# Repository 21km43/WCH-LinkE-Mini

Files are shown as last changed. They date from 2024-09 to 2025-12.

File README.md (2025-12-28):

# WCH-LinkE-Mini

This project is compatible with WCH-LinkE.

Boards is optimized for [JLCPCB](https://jlcpcb.com) (includes gerber, bom, cpl, and tooling holes). All components except the CH32V305, USB-C Connector, 3.3V LDO, and Tactile switches are Basic Parts.

## Requirements
* [KiCAD 9.0](https://www.kicad.org/)
* [Fabrication-Toolkit (Optional)](https://github.com/bennymeg/Fabrication-Toolkit)

## LICENSE
[MIT LICENSE](/LICENSE)

## Production files
- [Gerber](/production/WCH-LinkE-Mini_v1.4.0.zip)
- [BOM](/production/bom.csv)
- [Parts List](/production/bom.csv)

## Schematic and Board image
[Board schematic](WCH-LinkE-Mini.pdf)  
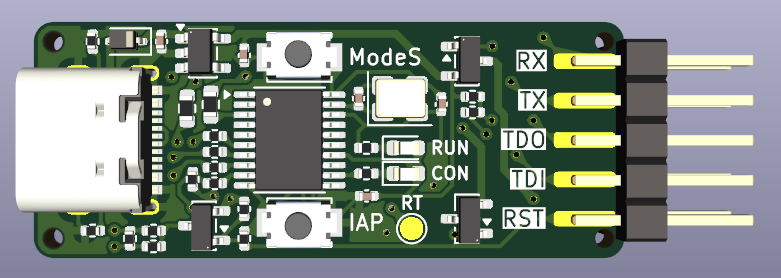
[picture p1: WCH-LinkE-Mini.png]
Board Image


IDC Connectors are available here
- [IDC-Header(socket)](https://www.digikey.jp/ja/products/detail/sullins-connector-solutions/SBH11-PBPC-D05-ST-BK/1990062)
- [IDC-Header(header)](https://www.digikey.jp/ja/products/detail/sullins-connector-solutions/SFH11-PBPC-D05-ST-BK/1990087)

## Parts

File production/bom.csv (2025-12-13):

Designator | Footprint | Quantity | Value | LCSC Part #
C1, C3 | 0402 | 2 | 22p | C1555
C2, C4 | 0402 | 2 | 1u | C52923
C5 | 0402 | 1 | 0.1u | C1525
D1 | 0603 | 1 | WHITE | C2290
D2 | 0603 | 1 | RED | C2286
D3 | D_SOD-323 | 1 | 1N5819WS | C191023
J1 | USB_C_Receptacle | 1 | USB_C_Receptacle_USB2.0_16P | C2988369
Q1, Q2 | SOT-23 | 2 | AO3401A | C15127
Q3 | SOT-23 | 1 | BSS138 | C7420339
R1, R2, R5, R6 | 0402 | 4 | 100 | C25076
R10, R13, R14, R17, R18 | 0402 | 5 | 10k | C25744
R11, R12, R8, R9 | 0402 | 4 | 5.1k | C25905
R15, R16 | 0402 | 2 | 330 | C25104
R3, R4 | 0603 | 2 | 270 | C22966
R7 | 0402 | 1 | 1k | C11702
SW1, SW2 | TS-1088-AR02016 | 2 | SW_Push | C720477
U1 | SOT-23-5 | 1 | RT9080-33GJ5 | C841192
U2 | TSSOP-20_4.4x6.5mm_P0.65mm | 1 | CH32V305FBP6 | C5123443
Y1 | Crystal_SMD_3225-4Pin_3.2x2.5mm | 1 | 12M | C9002

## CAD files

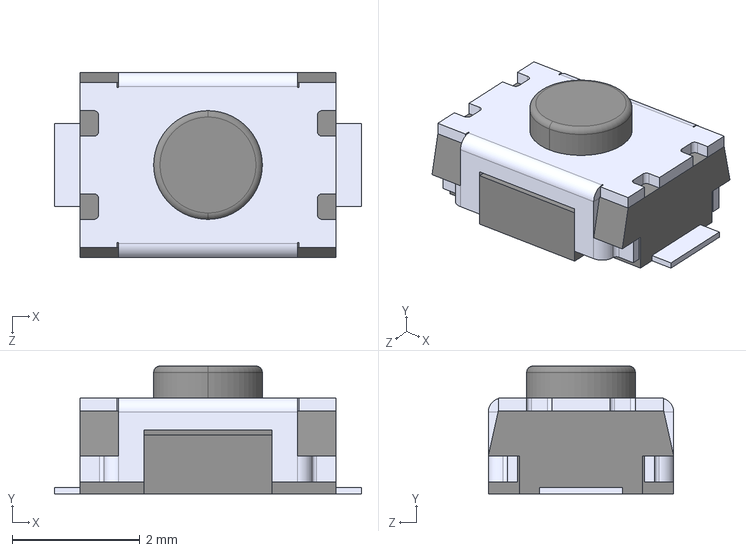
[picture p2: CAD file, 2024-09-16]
3d/TS-1088-AR02016.STEP
4.80 x 2.00 x 2.90 mm

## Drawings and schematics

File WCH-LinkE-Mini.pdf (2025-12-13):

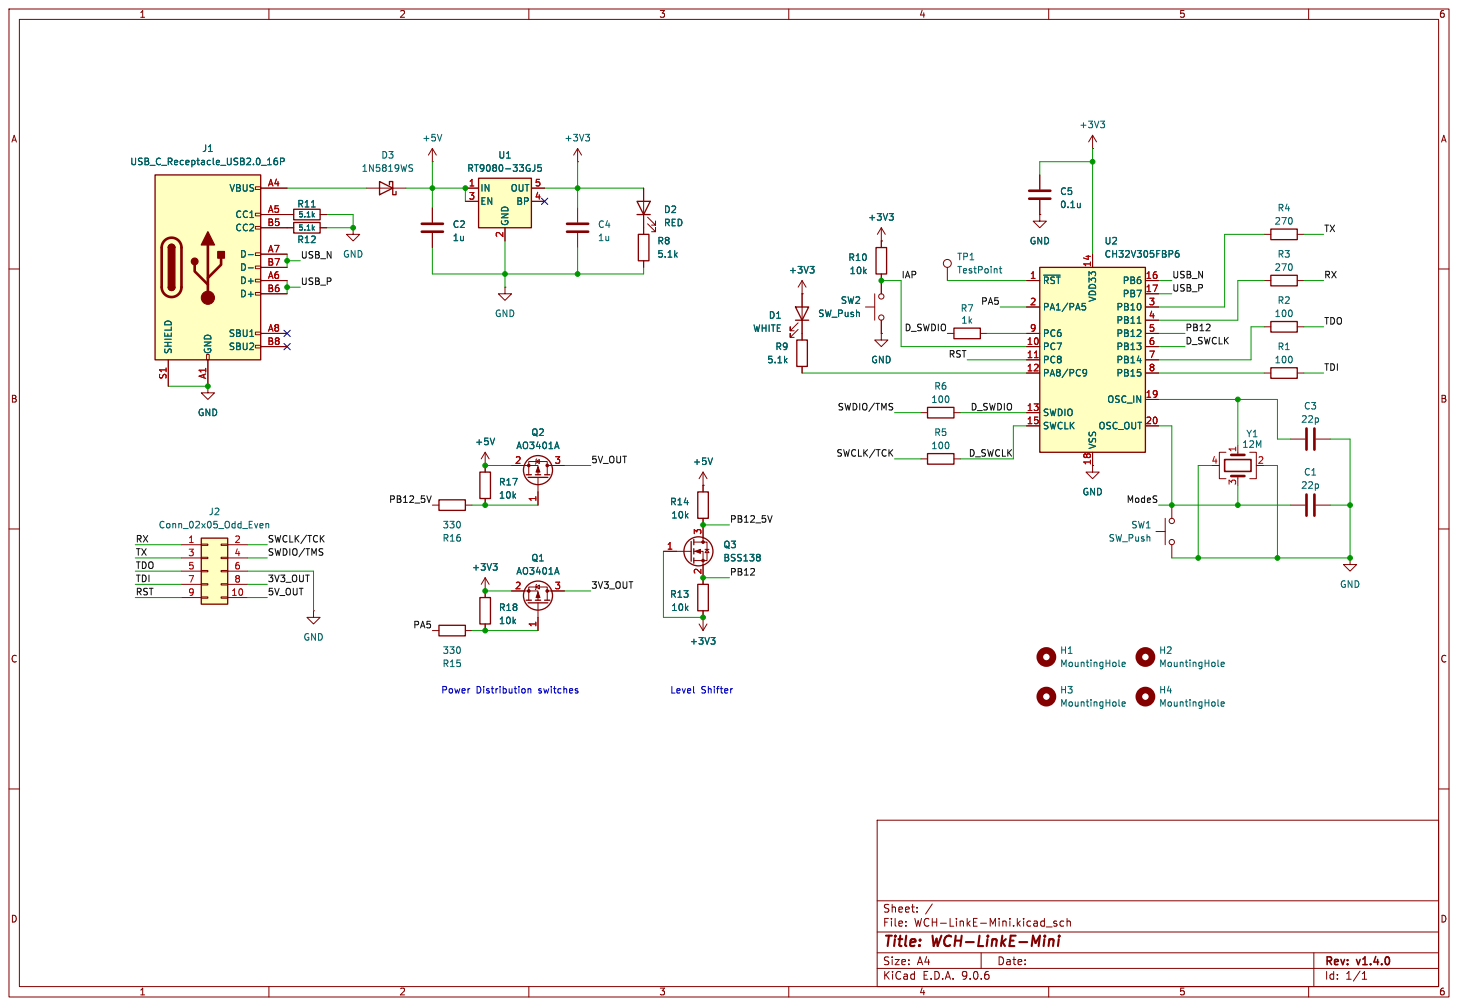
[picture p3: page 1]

Id: 1/1 Title: WCH-LinkE-Mini File: WCH-LinkE-Mini.kicad_sch Sheet: / R17

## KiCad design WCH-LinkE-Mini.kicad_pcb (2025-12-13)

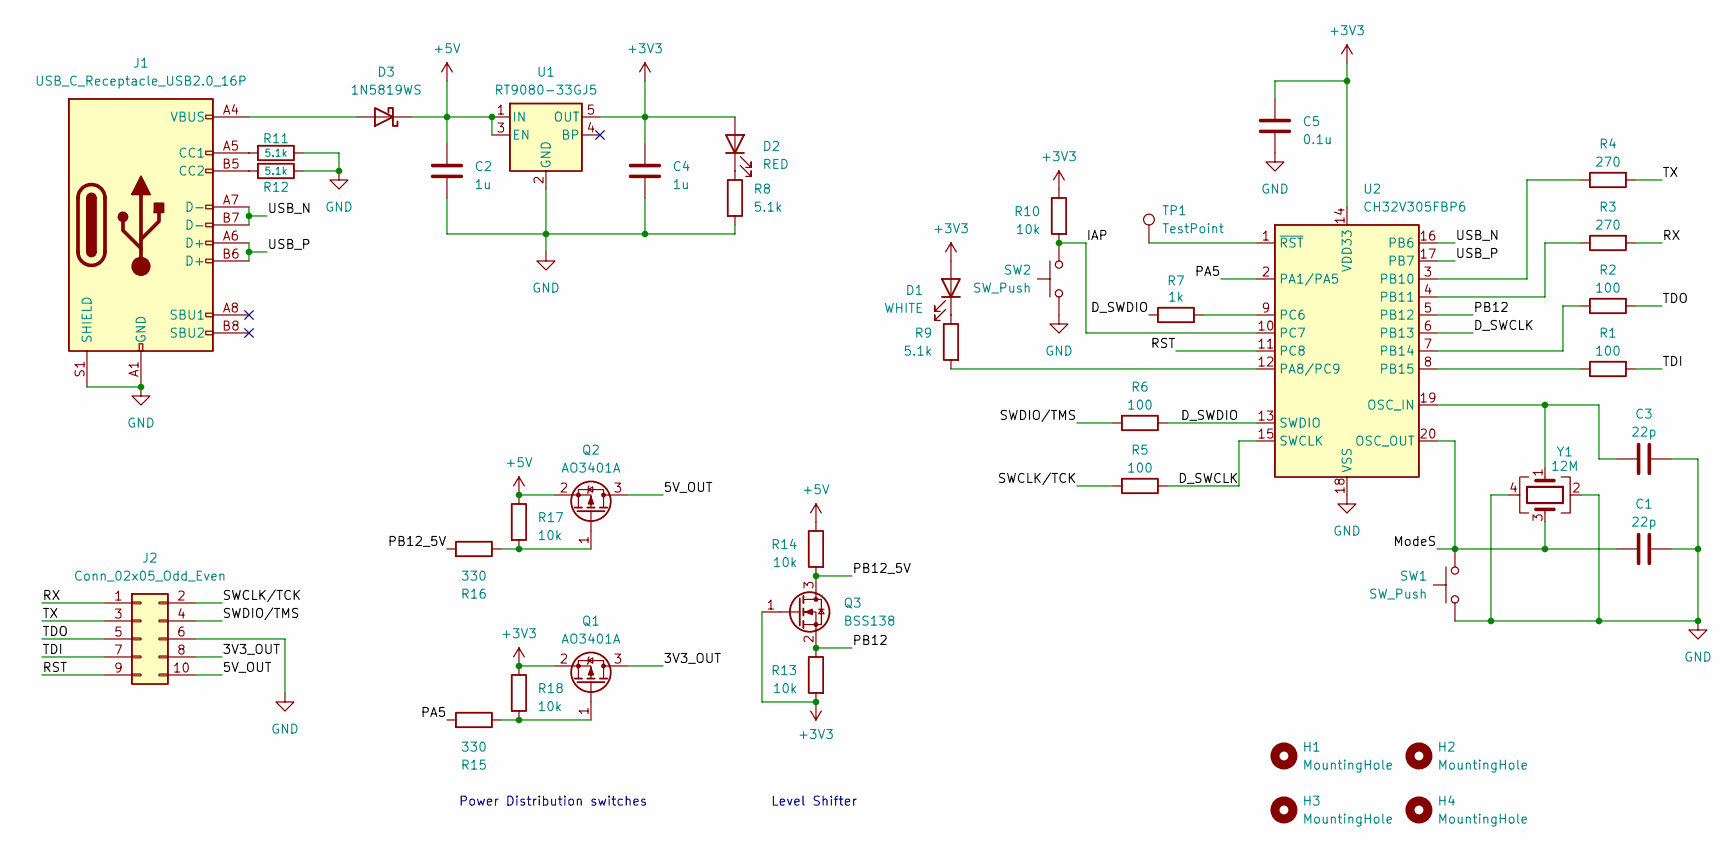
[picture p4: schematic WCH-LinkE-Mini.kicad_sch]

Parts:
C1, C3: 22p; C_0402_1005Metric; LCSC Part # C1555
C2, C4: 1u; C_0402_1005Metric; LCSC Part # C52923
C5: 0.1u; C_0402_1005Metric; LCSC Part # C1525
D1: WHITE; LED_0603_1608Metric; LCSC Part # C2290
D2: RED; LED_0603_1608Metric; LCSC Part # C2286
D3: 1N5819WS; D_SOD-323; LCSC Part # C191023
H1, H2, H3, H4: MountingHole; Tooling_Hole
J1: USB_C_Receptacle_USB2.0_16P; USB_C_Receptacle; LCSC Part # C2988369
J2: Conn_02x05_Odd_Even; PinHeader_2x05_P2.54mm_Horizontal_SMD
Q1, Q2: AO3401A; SOT-23; LCSC Part # C15127
Q3: BSS138; SOT-23; LCSC Part # C7420339
R1, R2, R5, R6: 100; R_0402_1005Metric; LCSC Part # C25076
R3, R4: 270; R_0603_1608Metric; LCSC Part # C22966
R7: 1k; R_0402_1005Metric; LCSC Part # C11702
R8, R9, R11, R12: 5.1k; R_0402_1005Metric; LCSC Part # C25905
R10, R13, R14, R17, R18: 10k; R_0402_1005Metric; LCSC Part # C25744
R15, R16: 330; R_0402_1005Metric; LCSC Part # C25104
SW1, SW2: SW_Push; TS-1088-AR02016; LCSC Part # C720477
TP1: TestPoint; TestPoint_Pad_D1.5mm
U1: RT9080-33GJ5; SOT-23-5; LCSC Part # C841192
U2: CH32V305FBP6; TSSOP-20_4.4x6.5mm_P0.65mm; LCSC Part # C5123443
Y1: 12M; Crystal_SMD_3225-4Pin_3.2x2.5mm; LCSC Part # C9002

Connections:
+3V3: C4.1, C5.1, D1.2 (A), D2.2 (A), Q1.2 (S), Q3.1 (G), R10.1, R13.2, R18.1, U1.5 (OUT), U2.14 (VDD33)
+5V: C2.1, D3.1 (K), Q2.2 (S), R14.1, R17.1, U1.1 (IN), U1.3 (EN)
/3V3_OUT: J2.8, Q1.3 (D)
/5V_OUT: J2.10, Q2.3 (D)
/D_SWCLK: R5.1, U2.6 (PB13), U2.15 (SWCLK)
/D_SWDIO: R6.1, R7.1, U2.13 (SWDIO)
/IAP: R10.2, SW2.1, U2.10 (PC7)
/ModeS: C1.2, SW1.1, U2.20 (OSC_OUT), Y1.3
/PA5: R15.2, U2.2 (PA1/PA5)
/PB12: Q3.2 (S), R13.1, U2.5 (PB12)
/PB12_5V: Q3.3 (D), R14.2, R16.2
/RST: J2.9, U2.11 (PC8)
/RX: J2.1, R3.2
/SWCLK/TCK: J2.2, R5.2
/SWDIO/TMS: J2.4, R6.2
/TDI: J2.7, R1.2
/TDO: J2.5, R2.2
/TX: J2.3, R4.2
/USB_N: J1.A7 (D-), J1.B7 (D-), U2.16 (PB6)
/USB_P: J1.A6 (D+), J1.B6 (D+), U2.17 (PB7)
GND: C1.1, C2.2, C3.1, C4.2, C5.2, J1.A1 (GND), J1.A12 (GND), J1.B1 (GND), J1.B12 (GND), J1.S1 (SHIELD), J2.6, R8.2, R11.1, R12.1, SW1.2, SW2.2, U1.2 (GND), U2.18 (VSS), Y1.2, Y1.4
unnamed: D1.1 (K), R9.1
unnamed: D2.1 (K), R8.1
unnamed: D3.2 (A), J1.A4 (VBUS), J1.A9 (VBUS), J1.B4 (VBUS), J1.B9 (VBUS)
unnamed: J1.A5 (CC1), R11.2
unnamed: J1.B5 (CC2), R12.2
unnamed: Q1.1 (G), R15.1, R18.2
unnamed: Q2.1 (G), R16.1, R17.2
unnamed: C3.2, U2.19 (OSC_IN), Y1.1
unnamed: R9.2, U2.12 (PA8/PC9)
unnamed: R4.1, U2.3 (PB10)
unnamed: R3.1, U2.4 (PB11)
unnamed: R2.1, U2.7 (PB14)
unnamed: R1.1, U2.8 (PB15)
unnamed: R7.2, U2.9 (PC6)
unnamed: TP1.1, U2.1 (~RST)

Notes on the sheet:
Power Distribution switches
Level Shifter

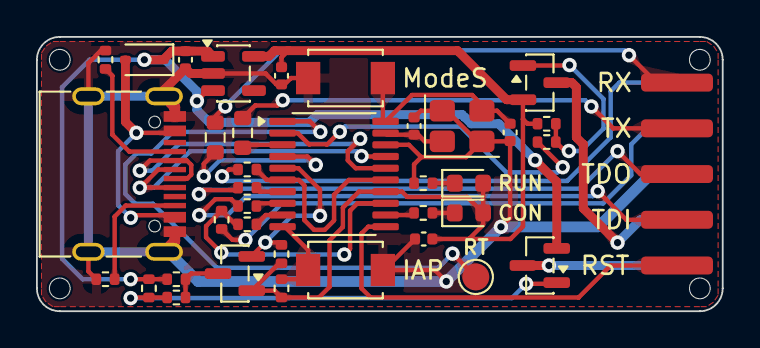
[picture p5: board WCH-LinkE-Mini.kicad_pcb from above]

Board: 2 copper layers, 38.1 x 15.2 mm, 41 parts (0 on the bottom side), 36 nets.

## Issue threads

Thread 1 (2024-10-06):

5V current limit

21km43, 2024-10-06:
3.3V -> Current limit is defined by regulator.
5V -> Current limit is defined PNP transistor?

21km43, 2024-10-07:
5V -> No limit

Closed 2024-10-07.

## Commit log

2024-09-17 csv position fix
    [WCH-LinkE.kicad_pcb, WCH-LinkE.kicad_sch, bom.csv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]
2024-09-25 move ch217k
    [WCH-LinkE.kicad_pcb, WCH-LinkE.kicad_sch, bom.csv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]
2024-09-26 position fix
    [WCH-LinkE.kicad_pcb, WCH-LinkE.kicad_sch, bom.csv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]
2024-09-26 version fix and show previous version
    [WCH-LinkE.kicad_pcb, WCH-LinkE.kicad_sch]
2024-09-26 fix trace width
    [WCH-LinkE.kicad_pcb, positions.csv]
2024-09-26 fix trace for gnd
    [WCH-LinkE.kicad_pcb, WCH-LinkE.kicad_sch, bom.csv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]
2024-09-28 fix button footprint
    [WCH-LinkE.kicad_pcb, positions.csv]
2024-10-02 remove solder pastefrom pinheader
    [WCH-LinkE.kicad_pcb]
2024-10-03 fix library and fillzone
    [WCH-LinkE.kicad_pcb, WCH-LinkE.kicad_sch, bom.csv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]
2024-10-06 v1.1.0 pre-release
    [WCH-LinkE.kicad_pcb, WCH-LinkE.kicad_sch, bom.csv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]
2024-10-06 fix resistor value
    [WCH-LinkE.kicad_pcb, WCH-LinkE.kicad_sch, bom.csv]
2024-10-06 rename project
    [WCH-LinkE-Mini.kicad_pcb, WCH-LinkE-Mini.kicad_sch]
2024-10-06 fix silk
    [WCH-LinkE-Mini.kicad_pcb]
2024-10-06 fix position
    [WCH-LinkE-Mini.kicad_pcb, WCH-LinkE-Mini.kicad_sch, positions.csv]
2024-10-09 change load switch structure
    [WCH-LinkE-Mini.kicad_pcb, WCH-LinkE-Mini.kicad_sch, bom.csv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]
2024-10-09 v1.1.0
    Update README.md
    Update README.md
    Update README.md
    Update README.md
    optimize
    fix path
    push test
    Update README.md
    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
    [WCH-LinkE-Mini.kicad_pcb, WCH-LinkE-Mini.kicad_sch, WCH-LinkE.kicad_pcb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]
2024-10-10 add idc connector explain
2024-10-10 add remarks
    [WCH-LinkE-Mini.kicad_sch]
2024-10-10 add resettable fuse
    [WCH-LinkE-Mini.kicad_pcb, WCH-LinkE-Mini.kicad_sch, bom.csv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]
2025-01-08 v1.3.0 (#3)
    * v1.3.0
    * Create review.yml
    * remove yml
    [WCH-LinkE-Mini.kicad_pcb, WCH-LinkE-Mini.kicad_sch, bom.csv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]
2025-01-08 Update production files
    [bom.csv, designators.csv, positions.csv]
2025-03-14 Update to KiCAD 9.0
    [WCH-LinkE-Mini.kicad_pcb, WCH-LinkE-Mini.kicad_sch]
2025-12-12 update symbols and footprints
    [WCH-LinkE-Mini.kicad_pcb, WCH-LinkE-Mini.kicad_sch]
